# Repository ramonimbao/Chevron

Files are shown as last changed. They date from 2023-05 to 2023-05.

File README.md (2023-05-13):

# Chevron

[][cc-by-nc-sa]

## Through-hole 40%-ish Keyboard

Chevron

Photo by bep#7432.

## Supported Layouts

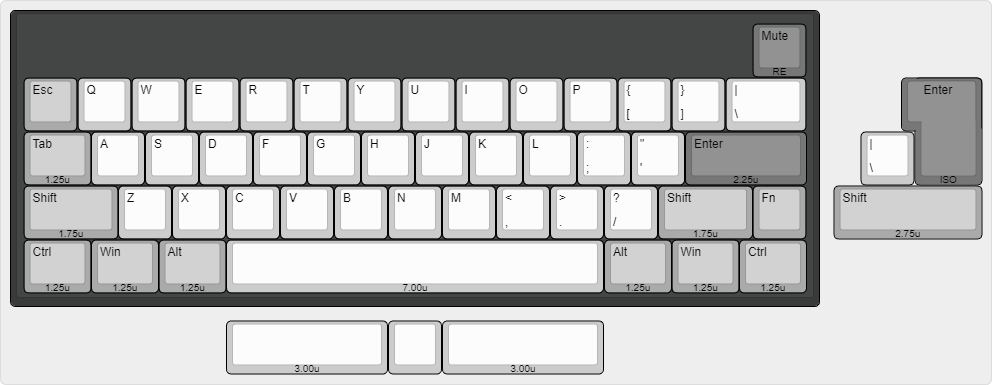
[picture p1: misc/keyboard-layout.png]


## Partslist
 |Count|Part|
 |-|-|
 |1|ATmega32A 40 pin DIP|
 |1|40 pin DIP socket|
 |1|HRO-TYPE-C-M-12|
 |1|500 mA polyfuse|
 |2|6mm momentary push buttons|
 |1|16 MHz quarz crystal|
 |1|4.7 uF electrolytic capacitor|
 |2|100 nF ceramic disk capacitor|
 |2|22 pF ceramic disk capacitor|
 |2|68 Ω resistor|
 |2|1.5 kΩ resistor|
 |2|5.1 kΩ resistor|
 |2|3.6 V zener diode|
 |53|universal switching diode|
 |1|EC11 encoder and knob (optional)|

## Files

There are three folders: `bottom`, `main-pcb`, `plate`. Inside each of them are a `gerbers` production folder, and a `kicad` source folder. Grab the gerber zip files from the `gerbers` folder.

The clear cover for the components is in the `misc` folder. There's also a foot you can laser cut to be used with the bottom. Needs M2 brass standoffs or screws to use.

## Firmware

https://github.com/qmk/qmk_firmware/tree/master/keyboards/rmi_kb/chevron

## Notes

High profile case files (seen in the photo) are not provided.

The KiCAD project was made with KiCAD 5.1.4, and have not been updated.

## License 

This work is licensed under a
[Creative Commons Attribution-NonCommercial-ShareAlike 4.0 International License][cc-by-nc-sa].

This design may be freely produced, modified, and manufactured for **PERSONAL USE ONLY** and may not be reproduced in physical form for public sale.

[][cc-by-nc-sa]

[cc-by-nc-sa]: http://creativecommons.org/licenses/by-nc-sa/4.0/
[cc-by-nc-sa-image]: https://licensebuttons.net/l/by-nc-sa/4.0/88x31.png
[cc-by-nc-sa-shield]: https://img.shields.io/badge/License-CC%20BY--NC--SA%204.0-lightgrey.svg

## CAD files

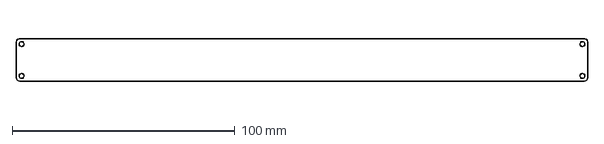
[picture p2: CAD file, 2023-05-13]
misc/cover-3mm.dxf
256.4 x 19.1 mm

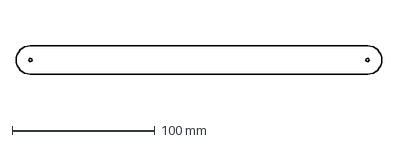
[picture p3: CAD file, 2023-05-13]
misc/feet-6mm.dxf
256.2 x 20.0 mm

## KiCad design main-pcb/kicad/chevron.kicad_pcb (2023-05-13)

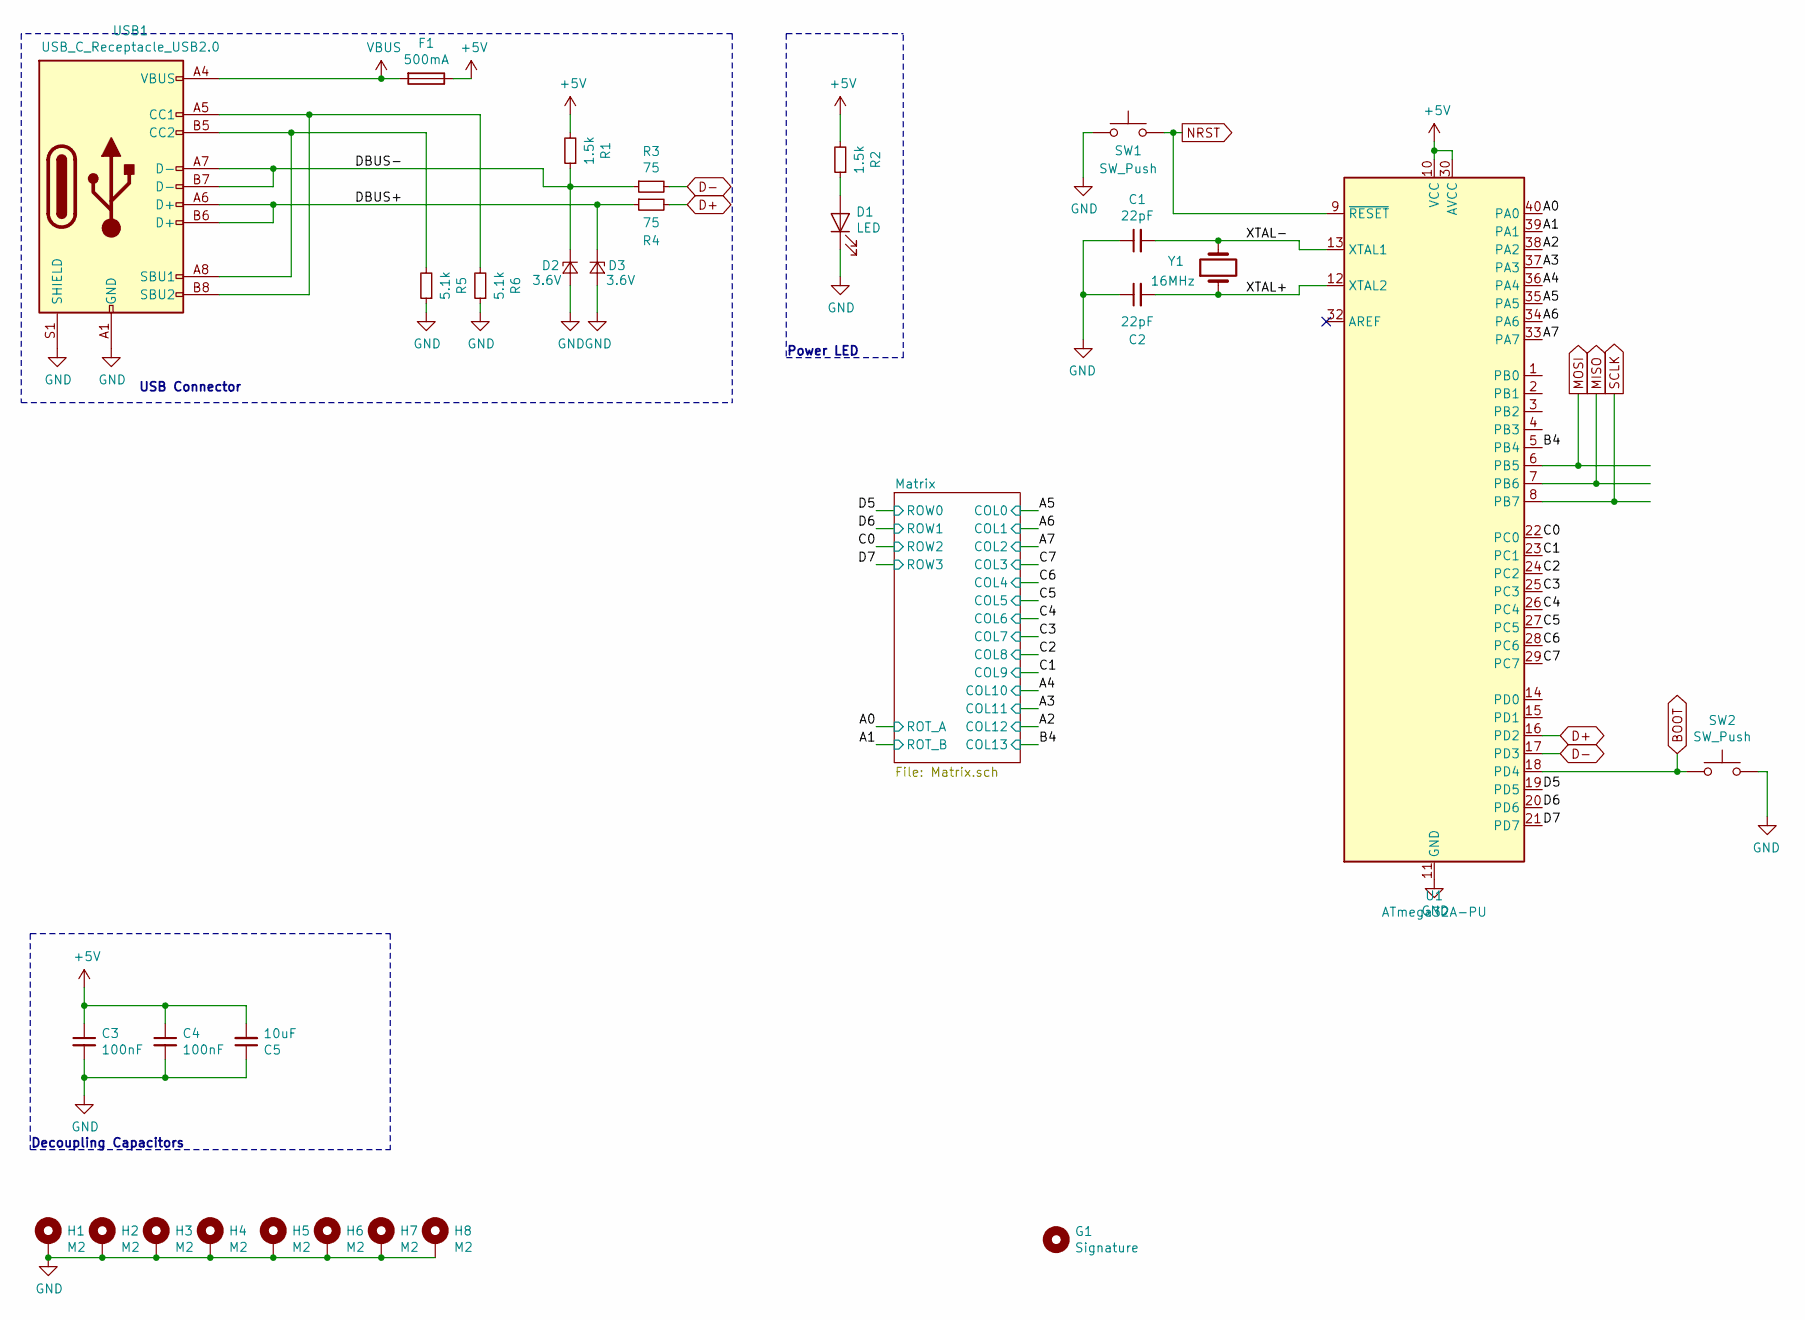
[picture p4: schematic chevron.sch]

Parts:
C1, C2: 22pF; C_Disc_D4.3mm_W1.9mm_P5.00mm
C3, C4: 100nF; C_Disc_D3.8mm_W2.6mm_P2.50mm
C5: 10uF; CP_Radial_D4.0mm_P1.50mm
D1: LED; LED_D3.0mm
D2, D3: 3.6V; D_DO-34_SOD68_P7.62mm_Horizontal
F1: 500mA; C_Disc_D5.0mm_W2.5mm_P5.00mm
G1: Signature
H1, H2, H3, H4, H5, H6, H7, H8: M2; MountingHole_2.2mm_M2_Pad_Via
R1, R2: 1.5k; R_Axial_DIN0204_L3.6mm_D1.6mm_P7.62mm_Horizontal
R3, R4: 75; R_Axial_DIN0204_L3.6mm_D1.6mm_P7.62mm_Horizontal
R5, R6: 5.1k; R_Axial_DIN0204_L3.6mm_D1.6mm_P7.62mm_Horizontal
SW1, SW2: SW_Push; SW_PUSH_6mm
U1: ATmega32A-PU; DIP-40_W15.24mm
USB1: USB_C_Receptacle_USB2.0; USB_C_GCT_USB4085
Y1: 16MHz; Crystal_HC49-4H_Vertical

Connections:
+5V: C3.1, C4.1, C5.2, F1.1, R1.2, R2.2, U1.10 (VCC), U1.30 (AVCC)
/A0: U1.40 (PA0); also elsewhere on the board
/A1: U1.39 (PA1); also elsewhere on the board
/A2: U1.38 (PA2); also elsewhere on the board
/A3: U1.37 (PA3); also elsewhere on the board
/A4: U1.36 (PA4); also elsewhere on the board
/A5: U1.35 (PA5); also elsewhere on the board
/A6: U1.34 (PA6); also elsewhere on the board
/A7: U1.33 (PA7); also elsewhere on the board
/B4: U1.5 (PB4); also elsewhere on the board
/C0: U1.22 (PC0); also elsewhere on the board
/C1: U1.23 (PC1); also elsewhere on the board
/C2: U1.24 (PC2); also elsewhere on the board
/C3: U1.25 (PC3); also elsewhere on the board
/C4: U1.26 (PC4); also elsewhere on the board
/C5: U1.27 (PC5); also elsewhere on the board
/C6: U1.28 (PC6); also elsewhere on the board
/C7: U1.29 (PC7); also elsewhere on the board
/D5: U1.19 (PD5); also elsewhere on the board
/D6: U1.20 (PD6); also elsewhere on the board
/D7: U1.21 (PD7); also elsewhere on the board
/DBUS+: D3.1 (K), R4.1, USB1.A6 (D+), USB1.B6 (D+)
/DBUS-: D2.1 (K), R1.1, R3.1, USB1.A7 (D-), USB1.B7 (D-)
/XTAL+: C2.2, U1.12 (XTAL2), Y1.1
/XTAL-: C1.2, U1.13 (XTAL1), Y1.2
BOOT: SW2.2, U1.18 (PD4)
D+: R4.2, U1.16 (PD2)
D-: R3.2, U1.17 (PD3)
GND: C1.1, C2.1, C3.2, C4.2, C5.1, D1.1 (K), D2.2 (A), D3.2 (A), H1.1, H2.1, H3.1, H4.1, H5.1, H6.1, H7.1, H8.1, R5.1, R6.1, SW1.1, SW2.1, U1.11 (GND), U1.31 (GND), USB1.A1 (GND), USB1.A12 (GND), USB1.B1 (GND), USB1.B12 (GND), USB1.S1 (SHIELD); also elsewhere on the board
MISO: U1.7 (PB6)
MOSI: U1.6 (PB5)
NRST: SW1.2, U1.9 (~RESET)
unnamed: D1.2 (A), R2.1
unnamed: R5.2, USB1.A8 (SBU1), USB1.B5 (CC2)
unnamed: R6.2, USB1.A5 (CC1), USB1.B8 (SBU2)
SCLK: U1.8 (PB7)
VBUS: F1.2, USB1.A4 (VBUS), USB1.A9 (VBUS), USB1.B4 (VBUS), USB1.B9 (VBUS)

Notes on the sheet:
USB Connector
Decoupling Capacitors
Power LED

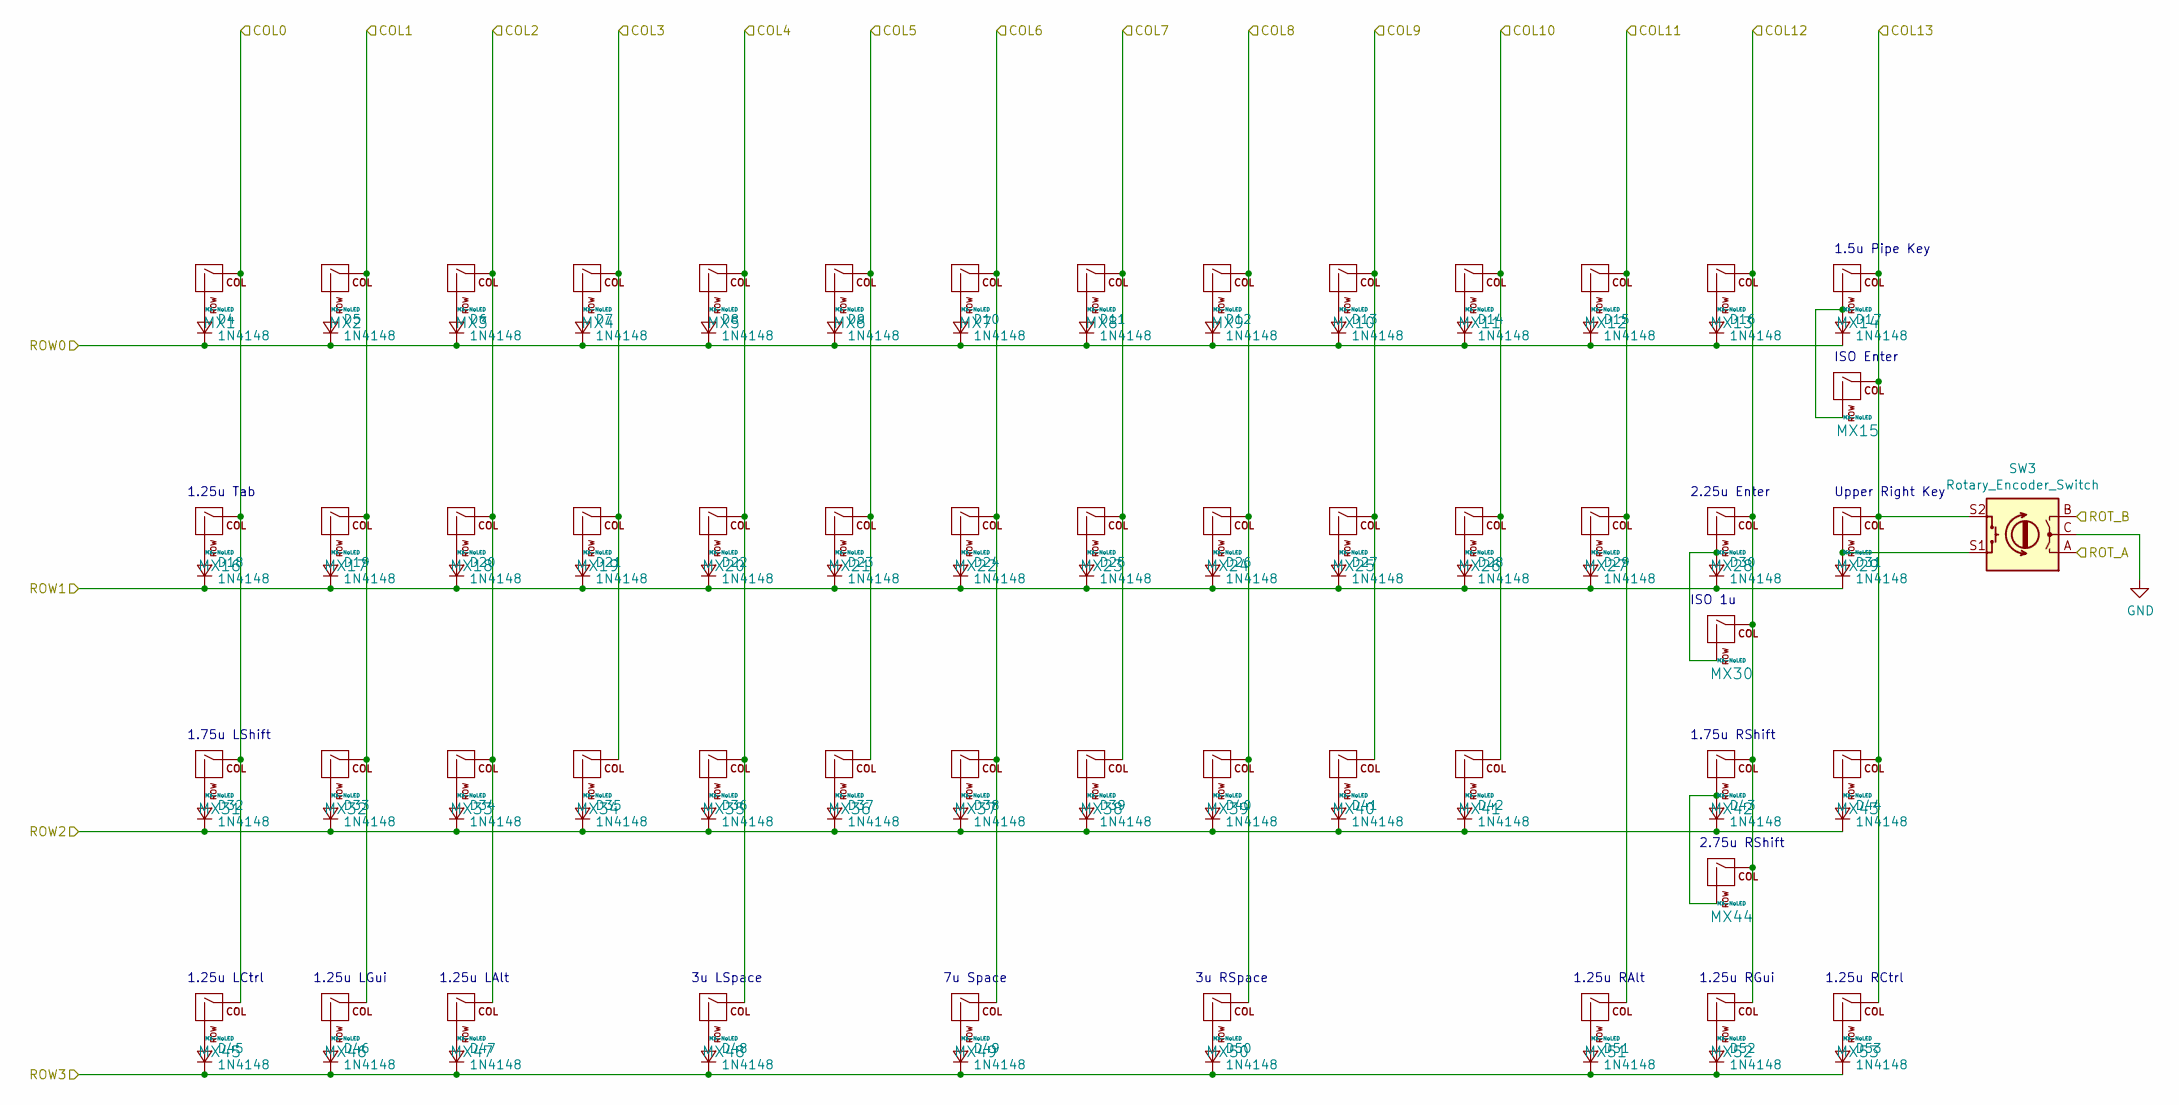
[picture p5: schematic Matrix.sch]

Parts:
D4, D5, D6, D7, D8, D9, D10, D11, D12, D13, D14, D15, D16, D17, D18, D19, D20, D21, D22, D23, D24, D25, D26, D27, D28, D29, D30, D31, D32, D33, D34, D35, D36, D37, D38, D39, D40, D41, D42, D43, D44, D45, D46, D47, D48, D49, D50, D51, D52, D53: 1N4148; D_DO-34_SOD68_P7.62mm_Horizontal_NoLabels
MX1, MX2, MX3, MX4, MX5, MX6, MX7, MX8, MX9, MX10, MX11, MX12, MX13, MX17, MX18, MX19, MX20, MX21, MX22, MX23, MX24, MX25, MX26, MX27, MX29, MX30, MX32, MX33, MX34, MX35, MX36, MX37, MX38, MX39, MX40, MX41, MX43: MX-NoLED; MXOnly-1U-NoLED
MX14: MX-NoLED; MXOnly-1.5U-NoLED
MX15: MX-NoLED; MXOnly-ISO-ROTATED-ReversedStabilizers-NoLED
MX16, MX45, MX46, MX47, MX51, MX52, MX53: MX-NoLED; MXOnly-1.25U-NoLED
MX28: MX-NoLED; MXOnly-2.25U-NoLED
MX31, MX42: MX-NoLED; MXOnly-1.75U-NoLED
MX44: MX-NoLED; MXOnly-2.75U-NoLED
MX48, MX50: MX-NoLED; MXOnly-3U-ReversedStabilizers-NoLED
MX49: MX-NoLED; MXOnly-7U-ReversedStabilizers-NoLED
SW3: Rotary_Encoder_Switch; RotaryEncoder_Alps_EC11E-Switch_Vertical_H20mm_Centered

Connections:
/A0: SW3.A; also elsewhere on the board
/A1: SW3.B; also elsewhere on the board
/A2: MX13.1 (COL), MX28.1 (COL), MX30.1 (COL), MX42.1 (COL), MX44.1 (COL), MX52.1 (COL); also elsewhere on the board
/A3: MX12.1 (COL), MX27.1 (COL), MX51.1 (COL); also elsewhere on the board
/A4: MX11.1 (COL), MX26.1 (COL), MX41.1 (COL); also elsewhere on the board
/A5: MX1.1 (COL), MX16.1 (COL), MX31.1 (COL), MX45.1 (COL); also elsewhere on the board
/A6: MX2.1 (COL), MX17.1 (COL), MX32.1 (COL), MX46.1 (COL); also elsewhere on the board
/A7: MX3.1 (COL), MX18.1 (COL), MX33.1 (COL), MX47.1 (COL); also elsewhere on the board
/B4: MX14.1 (COL), MX15.1 (COL), MX29.1 (COL), MX43.1 (COL), MX53.1 (COL), SW3.S2; also elsewhere on the board
/C0: D32.1 (K), D33.1 (K), D34.1 (K), D35.1 (K), D36.1 (K), D37.1 (K), D38.1 (K), D39.1 (K), D40.1 (K), D41.1 (K), D42.1 (K), D43.1 (K), D44.1 (K); also elsewhere on the board
/C1: MX10.1 (COL), MX25.1 (COL), MX40.1 (COL); also elsewhere on the board
/C2: MX9.1 (COL), MX24.1 (COL), MX39.1 (COL), MX50.1 (COL); also elsewhere on the board
/C3: MX8.1 (COL), MX23.1 (COL), MX38.1 (COL); also elsewhere on the board
/C4: MX7.1 (COL), MX22.1 (COL), MX37.1 (COL), MX49.1 (COL); also elsewhere on the board
/C5: MX6.1 (COL), MX21.1 (COL), MX36.1 (COL); also elsewhere on the board
/C6: MX5.1 (COL), MX20.1 (COL), MX35.1 (COL), MX48.1 (COL); also elsewhere on the board
/C7: MX4.1 (COL), MX19.1 (COL), MX34.1 (COL); also elsewhere on the board
/D5: D4.1 (K), D5.1 (K), D6.1 (K), D7.1 (K), D8.1 (K), D9.1 (K), D10.1 (K), D11.1 (K), D12.1 (K), D13.1 (K), D14.1 (K), D15.1 (K), D16.1 (K), D17.1 (K); also elsewhere on the board
/D6: D18.1 (K), D19.1 (K), D20.1 (K), D21.1 (K), D22.1 (K), D23.1 (K), D24.1 (K), D25.1 (K), D26.1 (K), D27.1 (K), D28.1 (K), D29.1 (K), D30.1 (K), D31.1 (K); also elsewhere on the board
/D7: D45.1 (K), D46.1 (K), D47.1 (K), D48.1 (K), D49.1 (K), D50.1 (K), D51.1 (K), D52.1 (K), D53.1 (K); also elsewhere on the board
GND: SW3.C; also elsewhere on the board
unnamed: D4.2 (A), MX1.2 (ROW)
unnamed: D5.2 (A), MX2.2 (ROW)
unnamed: D6.2 (A), MX3.2 (ROW)
unnamed: D7.2 (A), MX4.2 (ROW)
unnamed: D8.2 (A), MX5.2 (ROW)
unnamed: D9.2 (A), MX6.2 (ROW)
unnamed: D10.2 (A), MX7.2 (ROW)
unnamed: D11.2 (A), MX8.2 (ROW)
unnamed: D12.2 (A), MX9.2 (ROW)
unnamed: D13.2 (A), MX10.2 (ROW)
unnamed: D14.2 (A), MX11.2 (ROW)
unnamed: D15.2 (A), MX12.2 (ROW)
unnamed: D16.2 (A), MX13.2 (ROW)
unnamed: D17.2 (A), MX14.2 (ROW), MX15.2 (ROW)
unnamed: D18.2 (A), MX16.2 (ROW)
unnamed: D19.2 (A), MX17.2 (ROW)
unnamed: D20.2 (A), MX18.2 (ROW)
unnamed: D21.2 (A), MX19.2 (ROW)
unnamed: D22.2 (A), MX20.2 (ROW)
unnamed: D23.2 (A), MX21.2 (ROW)
unnamed: D24.2 (A), MX22.2 (ROW)
unnamed: D25.2 (A), MX23.2 (ROW)
unnamed: D26.2 (A), MX24.2 (ROW)
unnamed: D27.2 (A), MX25.2 (ROW)
unnamed: D28.2 (A), MX26.2 (ROW)
unnamed: D29.2 (A), MX27.2 (ROW)
unnamed: D30.2 (A), MX28.2 (ROW), MX30.2 (ROW)
unnamed: D31.2 (A), MX29.2 (ROW), SW3.S1
unnamed: D32.2 (A), MX31.2 (ROW)
unnamed: D33.2 (A), MX32.2 (ROW)
unnamed: D34.2 (A), MX33.2 (ROW)
unnamed: D35.2 (A), MX34.2 (ROW)
unnamed: D36.2 (A), MX35.2 (ROW)
unnamed: D37.2 (A), MX36.2 (ROW)
unnamed: D38.2 (A), MX37.2 (ROW)
unnamed: D39.2 (A), MX38.2 (ROW)
unnamed: D40.2 (A), MX39.2 (ROW)
unnamed: D41.2 (A), MX40.2 (ROW)
unnamed: D42.2 (A), MX41.2 (ROW)
unnamed: D43.2 (A), MX42.2 (ROW), MX44.2 (ROW)
unnamed: D44.2 (A), MX43.2 (ROW)
unnamed: D45.2 (A), MX45.2 (ROW)
unnamed: D46.2 (A), MX46.2 (ROW)
unnamed: D47.2 (A), MX47.2 (ROW)
unnamed: D48.2 (A), MX48.2 (ROW)
unnamed: D49.2 (A), MX49.2 (ROW)
unnamed: D50.2 (A), MX50.2 (ROW)
unnamed: D51.2 (A), MX51.2 (ROW)
unnamed: D52.2 (A), MX52.2 (ROW)
unnamed: D53.2 (A), MX53.2 (ROW)

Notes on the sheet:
ISO Enter
Upper Right Key
1.5u Pipe Key
1.25u Tab
2.25u Enter
ISO 1u
1.75u LShift
1.75u RShift
2.75u RShift
1.25u LCtrl
1.25u LGui
1.25u LAlt
3u LSpace
7u Space
3u RSpace
1.25u RAlt
1.25u RGui
1.25u RCtrl

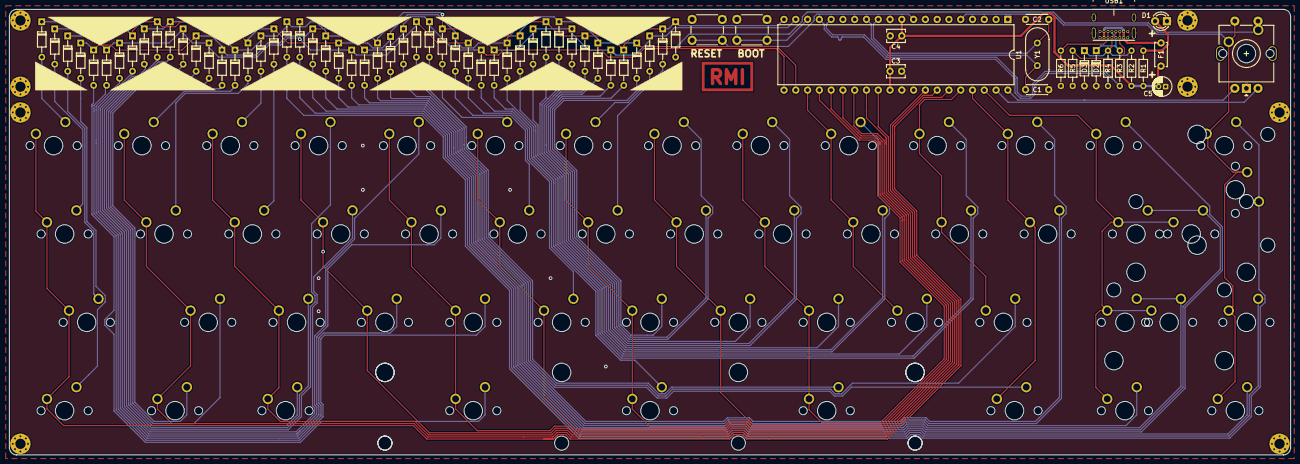
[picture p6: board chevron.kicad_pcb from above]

Board: 2 copper layers, 276.2 x 96.0 mm, 133 parts (0 on the bottom side), 84 nets.

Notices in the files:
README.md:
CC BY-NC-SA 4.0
